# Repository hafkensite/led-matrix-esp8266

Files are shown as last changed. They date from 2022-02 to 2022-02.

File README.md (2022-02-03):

# WS2812 led matrix panel with ESP8266 controller.

## Used libs

- [FastLED](https://github.com/FastLED/FastLED) to send the values to the WS2812 LEDs. The XY support is based on one of the examples.
- [WiFiManager](https://github.com/tzapu/WiFiManager) to make it easy to connect it to the wifi.

## Protocol

The ESP reads 16x16x3 bytes in a single UDP packet on port 5060, and sets all the pixels to the byte values.

## Commands

### Set all to black

```bash
head -c 768 /dev/zero | socat -t 0 - UDP:192.168.2.35:5060
```

### Set to random colors

```bash
head -c 768 /dev/urandom | socat -t 0 - UDP:192.168.2.35:5060
```

### Send an image, cropped square and resized to 16x16.

```bash
convert image.png -background black -resize 16x16^ -gravity center -extent 16x16 RGB:- | socat -t 0 - UDP:192.168.2.35:5060
```

```bash
ffmpeg \
    -re \
    -i sample.mkv -vf "crop=in_h:in_h,scale=16:16,eq=brightness=-0.2" \
    -vcodec rawvideo \
    -pix_fmt rgb24 \
    -f rawvideo \
    -r 30 \
    udp://192.168.2.35:5060
```

## 3D-printable matrix

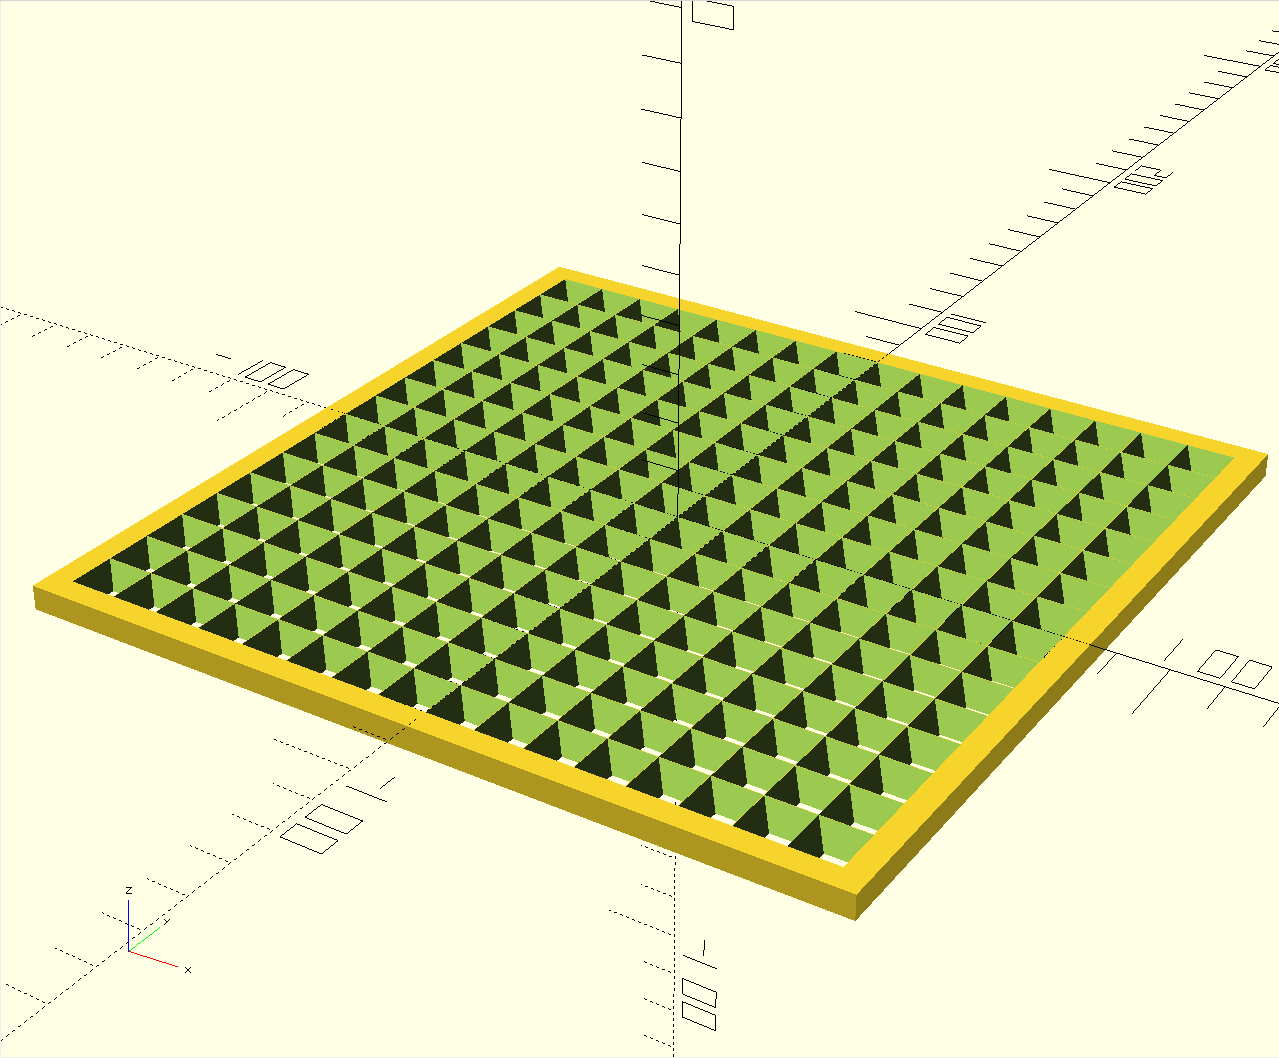
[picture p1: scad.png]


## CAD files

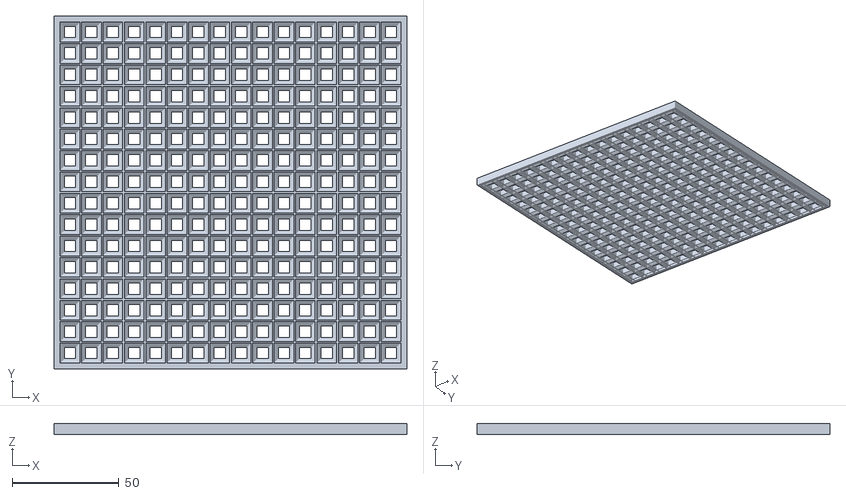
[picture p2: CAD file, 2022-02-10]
matrix.stl
165.0 x 165.0 x 5.00

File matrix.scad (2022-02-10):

dist = 10;   // 1cm spacing
ledsize = 6; // 5050 led + 1mm
height = 5;  // Height of the entire thing
w = 16;
h = 16;
extr_width=0.4; // Nossle width
border = 2.5;

// Calculations
straight_h = height*.7;
angle_h = height - straight_h;
echo("Angled bit height", angle_h);
angle_w = (dist - ledsize)/2;
edge_len = sqrt(angle_h*angle_h + angle_w*angle_w)+0.4;
angle_a = atan(angle_w / angle_h  );

intersection() {
    translate([-border,-border,0])
    cube([w*dist+border*2, h*dist+border*2, height]);
    
    union()
    {
        for (x = [0:h]) {
            translate([dist*w/2, x*dist, height-straight_h/2])
            cube([w*dist, extr_width*2, straight_h],center=true);
            
            translate([dist*w/2, x*dist+angle_w/2, angle_h/2-0.1])
            rotate([angle_a,0,0])
            cube([w*dist, extr_width*1.5, edge_len],center=true);
            
            translate([dist*w/2, x*dist-angle_w/2, angle_h/2-0.1])
            rotate([-angle_a,0,0])
            cube([w*dist, extr_width*1.5, edge_len],center=true);
        }
       for (y = [0:w]) {
            translate([y*dist, dist*h/2, height-straight_h/2])
            cube([extr_width*2, h*dist, straight_h],center=true);

            translate([y*dist+angle_w/2, dist*h/2, angle_h/2-0.1])
            rotate([0,-angle_a,0])
            cube([extr_width*1.5, h*dist, edge_len],center=true);
            
            translate([y*dist-angle_w/2, dist*h/2, angle_h/2-0.1])
            rotate([0,angle_a,0])
            cube([extr_width*1.5, h*dist, edge_len],center=true);
        }
        // border
        translate([-border, -border,0])
        cube([border, h*dist+border*2, height]);
        translate([w*dist, -border,0])
        cube([border, h*dist+border*2, height]);
        translate([-border, -border,0])
        cube([w*dist+border*2, border, height]);
        translate([-border, h*dist,0])
        cube([w*dist+border*2, border, height]);
    }
}

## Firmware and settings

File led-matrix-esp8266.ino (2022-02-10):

#include <FastLED.h>

#include <WiFiManager.h> // https://github.com/tzapu/WiFiManager
WiFiManager wm;

#define LED_PIN D3

#define COLOR_ORDER GRB
#define CHIPSET WS2811

#define BRIGHTNESS 16

// Params for width and height
#define MATRIX_WIDTH 16
#define MATRIX_HEIGHT 16

#define NUM_LEDS (MATRIX_WIDTH * MATRIX_HEIGHT)
CRGB leds[NUM_LEDS];

WiFiUDP Udp;
char incomingPacket[MATRIX_WIDTH * MATRIX_HEIGHT * 3];

uint16_t XY(uint8_t x, uint8_t y)
{
  if (y & 0x01)
  {
    // Odd rows run forwards
    return (y * MATRIX_WIDTH) + x;
  }

  // Even rows run backwards
  uint8_t reverseX = (MATRIX_WIDTH - 1) - x;
  return (y * MATRIX_WIDTH) + reverseX;
}

void loop()
{

  int packetSize = Udp.parsePacket();
  if (packetSize)
  {
    //    Serial.printf("Received %d bytes from %s, port %d\n", packetSize, Udp.remoteIP().toString().c_str(), Udp.remotePort());
    int len = Udp.read(incomingPacket, NUM_LEDS * 3);
    if (len == NUM_LEDS * 3)
    {
      for (uint8_t y = 0; y < MATRIX_HEIGHT; y++)
      {
        for (uint8_t x = 0; x < MATRIX_WIDTH; x++)
        {
          int start = (y * MATRIX_HEIGHT + x) * 3;
          leds[XY(x, y)] = CRGB(
              incomingPacket[start + 0],
              incomingPacket[start + 1],
              incomingPacket[start + 2]);
        }
      }
      FastLED.show();
    }
  }
}

void DrawOneFrame(uint8_t startHue8, int8_t yHueDelta8, int8_t xHueDelta8)
{
  uint8_t lineStartHue = startHue8;
  for (uint8_t y = 0; y < MATRIX_HEIGHT; y++)
  {
    lineStartHue += yHueDelta8;
    uint8_t pixelHue = lineStartHue;
    for (uint8_t x = 0; x < MATRIX_WIDTH; x++)
    {
      pixelHue += xHueDelta8;
      leds[XY(x, y)] = CHSV(pixelHue, 255, 255);
    }
  }
}

void setup()
{
  FastLED.addLeds<CHIPSET, LED_PIN, COLOR_ORDER>(leds, NUM_LEDS).setCorrection(TypicalSMD5050);
  FastLED.setBrightness(BRIGHTNESS);
  FastLED.setCorrection(TypicalSMD5050);
  WiFi.setSleepMode(WIFI_MODEM_SLEEP);
  FastLED.clear();
  DrawOneFrame(1, 32, 192);
  FastLED.show();

  Serial.begin(115200);
  WiFi.mode(WIFI_STA);
  //  wm.resetSettings();

  if (wm.autoConnect("AutoConnectAP"))
  {
    Serial.println("connected...yeey :)");
    Udp.begin(5060);
  }
  else
  {
    Serial.println("Failed to connect");
    wm.reboot();
  }
}

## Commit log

2022-02-06 Update 3d design to be faster to print
    [matrix.scad, matrix.stl]
2022-02-08 Repare for test print
    [matrix.scad]
2022-02-08 3d print to 16x16 size with 0.4mm nossle and 2 layers minimal.
    [matrix.scad]
2022-02-10 Updated 3d model after test print
    [matrix.scad, matrix.stl, prusa-slicer-project.3mf]
2022-02-10 Fix flickering and unreliable FastLED.show by setting wifi sleepmode
    [led-matrix-esp8266.ino]
